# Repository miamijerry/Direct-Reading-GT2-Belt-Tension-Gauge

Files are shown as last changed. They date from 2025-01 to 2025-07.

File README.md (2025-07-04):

# 7/4/2025 Added 
# Relative Magnet Force Comparator



# and
# Super Simply Magnet Force Measurement Tool



# _________________________________________________________________________

# _________________________________________________________________________

# 7/1/2025 Added files to convert this GT2 belt tension gauge to a Magnet Force Measurement Tool

10x5mm N52 magnet from JC Magnetics

# 10x5mm N52 magnet from JC Magnetics being measure for actual repelling force in lbs.



# _________________________________________________________________________

# _________________________________________________________________________

# V2 of Direct Reading GT2 Belt Tension Gauge







# Direct-Reading-GT2-Belt-Tension-Gauge
A method to accurately determine GT2 belt tension

Math Formula

Per the 1/64 deflection per inch of belt method

I created three STL's for V2; Front Pins, Sled, and Deflection Knob. These mount a Force Gauge

To set the amount of belt deflection, I am using a #10-32 threaded rod attached to the Deflection Knob

Each 1/2 turn of a #10-32 screw equals 1/64 of an inch.

The first beta version was not accurate, and it was determined that the friction of the belt against the pins was creating incorrect reading.

The first working version (V1) assembly used GT2 idler pulleys for the pins. The results have been within 0.2 pounds.

I am not releasing V1, because V2 was much better.

Thanks to DIYshift, who's tension gauge was used to model the Front stl.

https://github.com/Diyshift/3D-Printer/tree/main/GT2%20Belt%20Tension%20Meter

# Recommended GT2 Belt Tension

Hard to find this information, 

From https://www.sdp-si.com/D265/PDF/D265T050.pdf

Recommended Tension

and

From https://github.com/Diyshift/3D-Printer/blob/main/GT2%20Belt%20Tension%20Meter/Manual/GT2_Tensiometer_Manual.pdf

DIYshift tension guideline; 
# Voron - A/B 6mm Belts Min 2.0 lbs Max 3.5 lbs, Voron belted Z 9mm belt min 4.5 lbs Max 6.0 lbs

# Verifying that this gauge is reading correctly

Hang a known weight from a section of GT2 belt

Following operating procedure

Verify that the gauge reports the same value as the known weight

# License
Shield: [][cc-by-nc-sa]![Recommended Tension]

This work is licensed under a
[Creative Commons Attribution-NonCommercial-ShareAlike 4.0 International License][cc-by-nc-sa].

[][cc-by-nc-sa]

[cc-by-nc-sa]: http://creativecommons.org/licenses/by-nc-sa/4.0/
[cc-by-nc-sa-image]: https://licensebuttons.net/l/by-nc-sa/4.0/88x31.png
[cc-by-nc-sa-shield]: https://img.shields.io/badge/License-CC%20BY--NC--SA%204.0-lightgrey.svg

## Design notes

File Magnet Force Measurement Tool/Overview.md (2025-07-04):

Convert the GT2 Belt Tension Gauge to a precise Magnet Force Measurement Tool

10x5mm N52 magnet from JC Magnetics

There are two types of inner magnet carriers, one internally threaded and one slip on.

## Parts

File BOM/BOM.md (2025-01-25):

Direct Reading 2GT Belt Tension Meter V2

Bill of Material

1ea 10-32 heat insert 10-32 x 3/8 tall x 7.1mm diameter (Set in the Sled)
1ea 10-32 x 6" Threaded Rod, will cut shorter
2ea M4 x 6mm flat head countersunk screw (Attaches Force Gauge)
2ea M4 x 6mm Socket Head Screw screw (Attaches Force Gauge and acts as a stop)
1ea 50N Digital Force Gauge Push Pull Gauge Portable Force Meter with Units N/LB/Kg/Oz, 
Auto Backlit LCD, for Lab Tension and Compression Load Plug Force Destructive Tests.
https://www.amazon.com/dp/B09V11R7Y2?ref=ppx_yo2ov_dt_b_fed_asin_title&th=1
3ea 10-32 fiber locknuts
2ea M5 washers aprox 14mm OD (To create a thrust surface on the Sled stl) 

Front Heat Insert
2ea M3 x 8mm tall x 4.7 diameter heat insert
2ea 3.1mm ID x 5mm OD x 10mm tall M3 spacer
https://www.amazon.com/dp/B0CQDWT42S?ref=ppx_yo2ov_dt_b_fed_asin_title&th=1
2ea M3 washers 9mm OD
2ea M3 x 18mm socket head cap screw
2sets GT2 Idler Pulleys, 2ea smooth and 2ea with teeth
https://www.amazon.com/gp/product/B0B1ZH9WC5/ref=ppx_yo_dt_b_asin_title_o04_s00?ie=UTF8&th=1

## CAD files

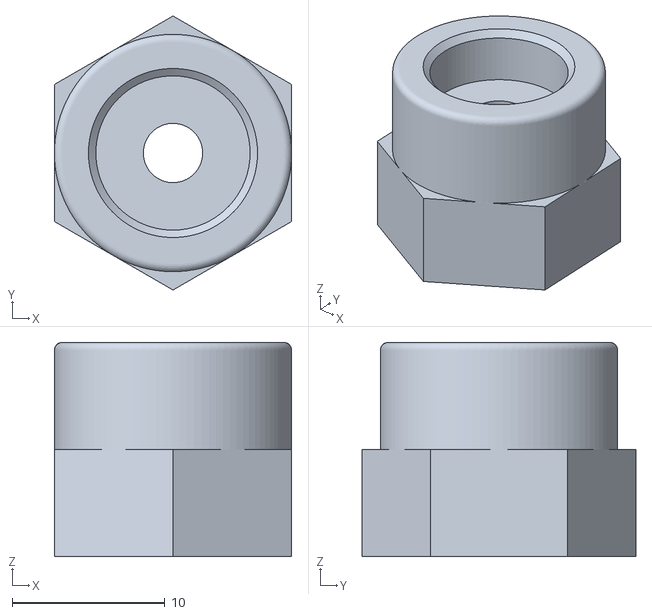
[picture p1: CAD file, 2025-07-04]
Magnet Force Measurement Tool/97_Percent_Scaled_R2_10x5mm internally threaded magnet carrier.stl
15.5 x 17.9 x 14.0

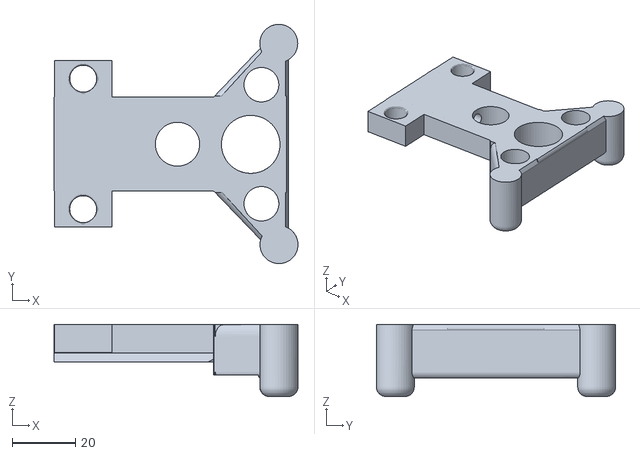
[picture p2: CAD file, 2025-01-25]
R4_Front_Heat_Insert_V2.stl
77.0 x 75.5 x 22.7

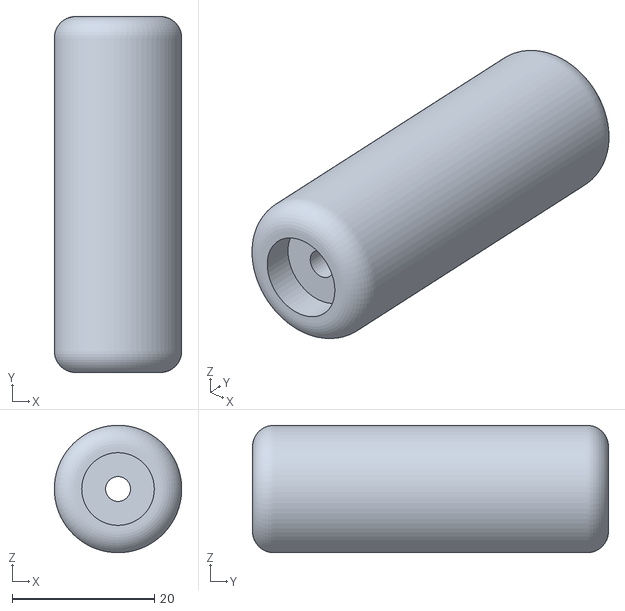
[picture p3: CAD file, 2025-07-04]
Super Simple Magnet Force Tester/R2_10x5mm magnet PCV pipe carrier sized for one half inch schedule 20 PVC pipe.stl
17.9 x 50.0 x 17.9

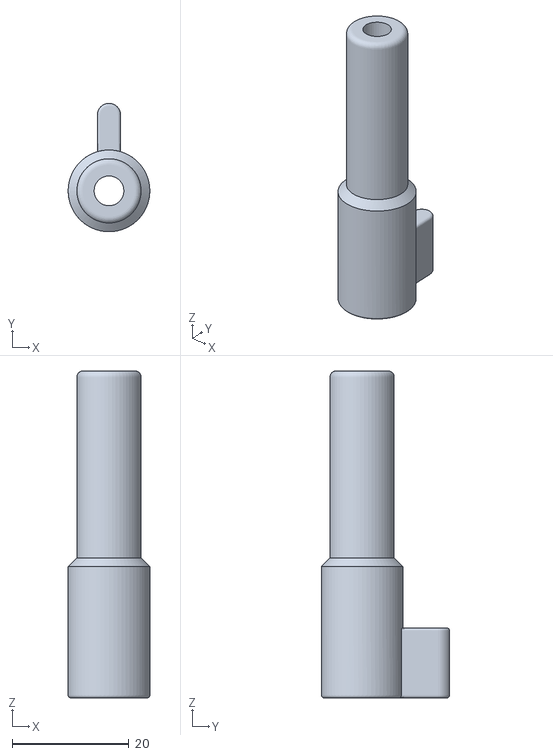
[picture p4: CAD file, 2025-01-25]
Deflection_Knob.stl
14.0 x 22.0 x 56.0

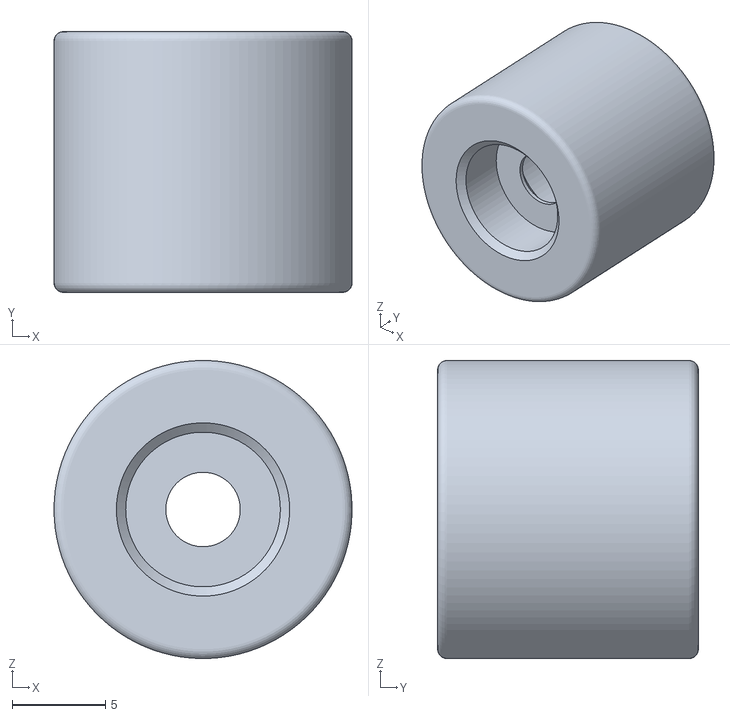
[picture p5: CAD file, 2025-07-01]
Magnet Force Measurement Tool/8x5mm magnet carrier.stl
16.0 x 14.0 x 16.0

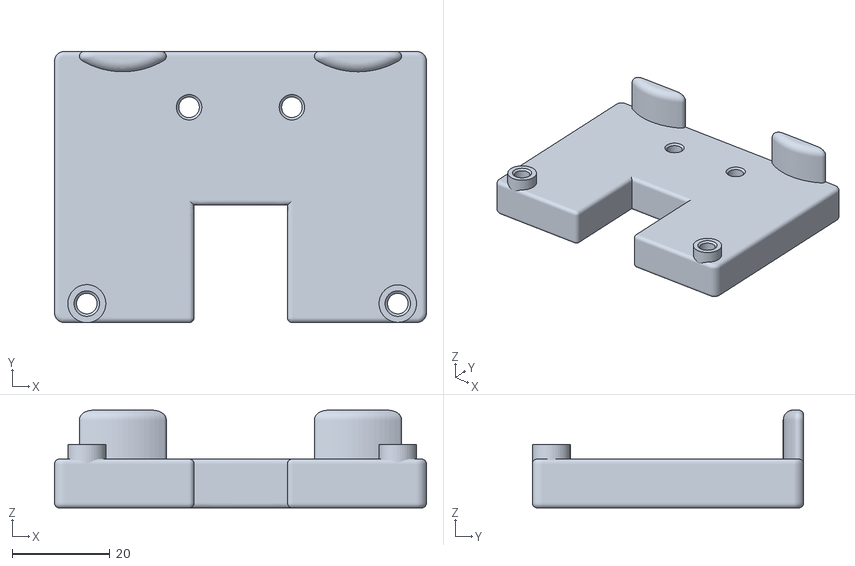
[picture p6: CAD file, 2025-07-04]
Relative Magnet Force Comparator/Baseplate.stl
76.0 x 55.4 x 20.0

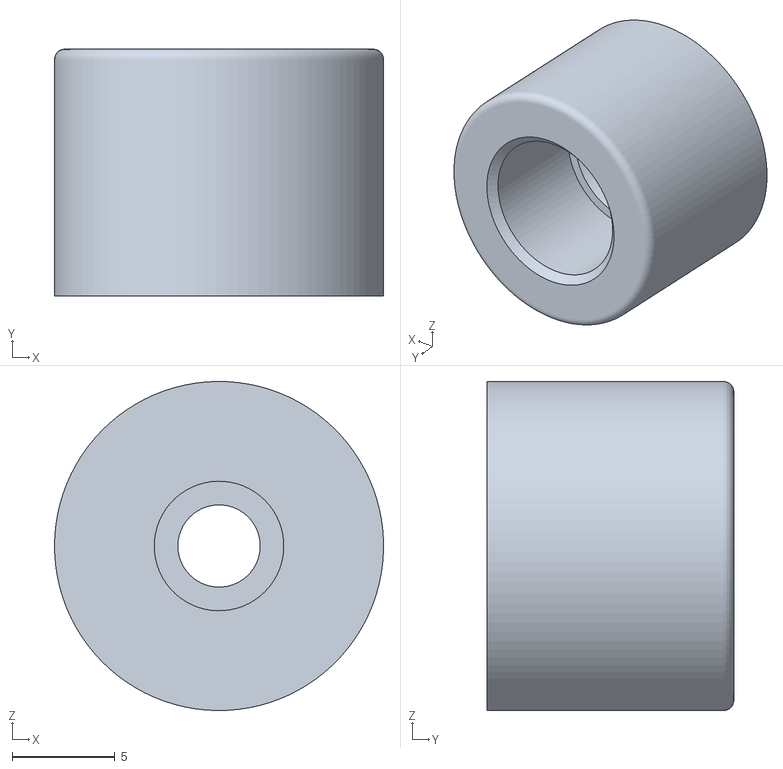
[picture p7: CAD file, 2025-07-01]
Magnet Force Measurement Tool/6x3mm magnet carrier.stl
16.0 x 12.0 x 16.0

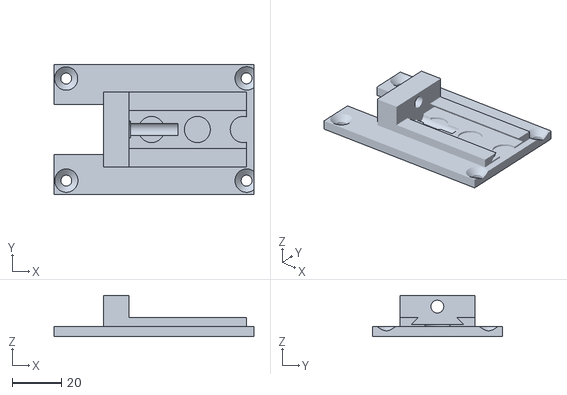
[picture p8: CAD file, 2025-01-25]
R4_Sled_V2.stl
81.0 x 52.5 x 16.6

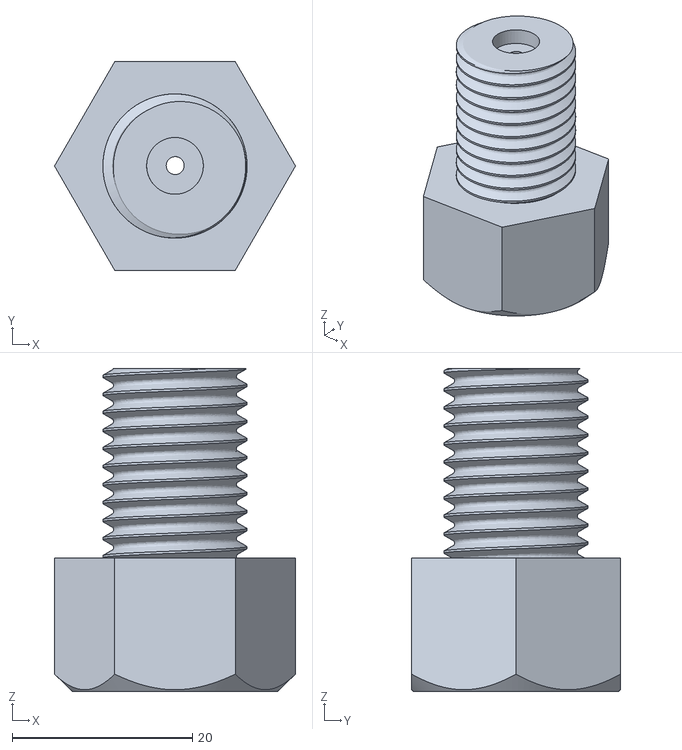
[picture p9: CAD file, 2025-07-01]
Relative Magnet Force Comparator/R6_6x3mm magnet threaded carrier.stl
26.7 x 23.2 x 35.8

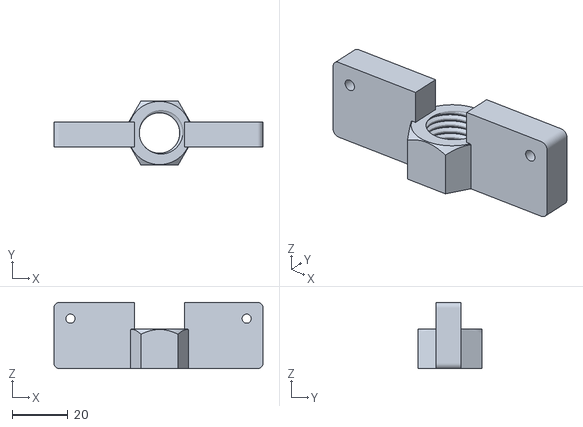
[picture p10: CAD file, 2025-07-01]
Relative Magnet Force Comparator/R4_Threaded_Bridge.stl
75.3 x 23.2 x 23.9

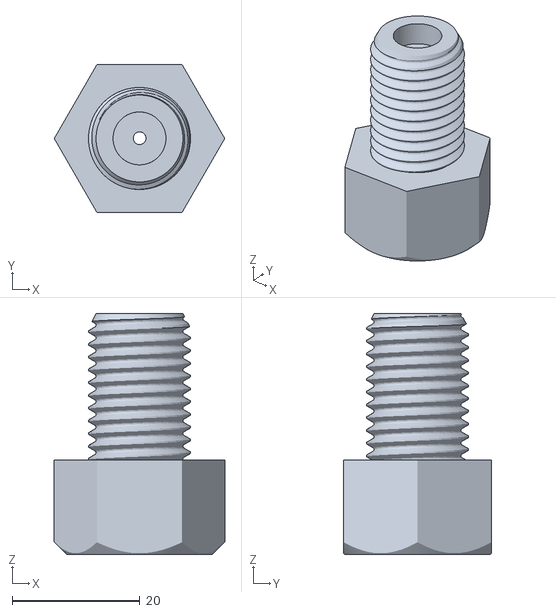
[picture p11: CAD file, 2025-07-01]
Relative Magnet Force Comparator/R5_8x5mm magnet threaded carrier.stl
26.7 x 23.2 x 37.8

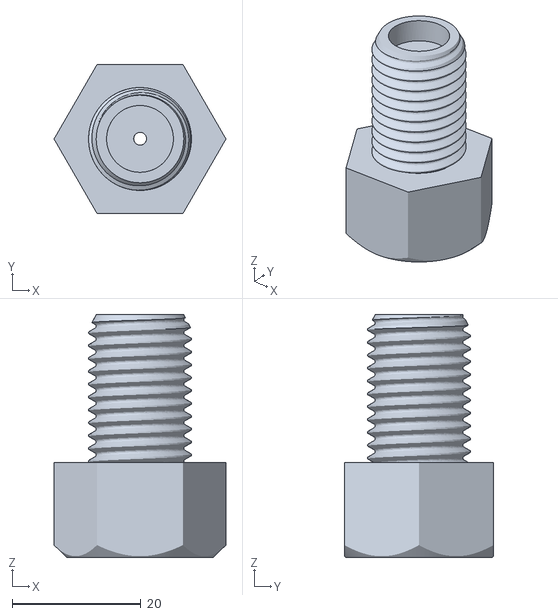
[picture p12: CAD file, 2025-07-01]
Relative Magnet Force Comparator/R5_10x5mm magnet threaded carrier.stl
26.7 x 23.2 x 37.8

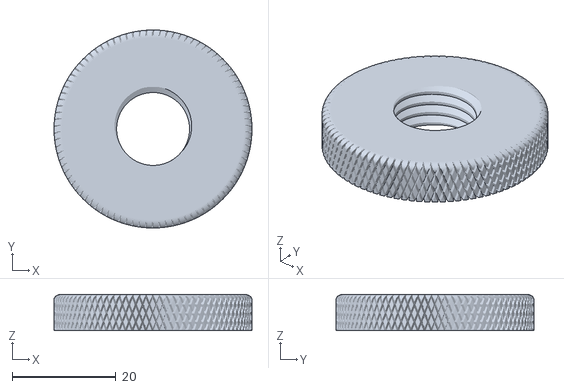
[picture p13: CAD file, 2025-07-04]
Relative Magnet Force Comparator/M16 Knurled Jam Nut.stl
38.1 x 38.1 x 7.00

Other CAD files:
Magnet Force Measurement Tool/R2_10x5mm magnet carrier.stl

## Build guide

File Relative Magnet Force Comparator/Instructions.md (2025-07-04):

Create a "Relative Magnet Force Comparator" from YesterdaysCoffee Belt Tension Meter;
https://www.printables.com/model/634190-gt2-belt-tension-meter-wbearings

# Tool is only for comparing magnets, will show relative weaker or stronger magnets then the magnet used to set the pointer.



Parts needed to assemble this tool.



Mount the Belt Tension Meter to the printed Backplate with longer screws M3x18mm work fine. (Note the M6x10 stainless grub screw threaded into the YeasterdaysCoffer meter, this grub screw should be nylon and more like M6x14mm long)



Advance the thread magnet carrier until the pointer reads 3.0 (This is relative, only good for comparating) 

M16 Knurled Jam Nut

At this point the threaded carrier needs to be set to this depth with a jam nut.

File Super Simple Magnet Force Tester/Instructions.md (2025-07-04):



1) Start with a tube, a plunger, two magnet carriers and any digital scale. (In this picture I am using 390mm long 1/2" schedule 20 PVC water pipe for the tube)

  

2) I glued the two magnets in the carriers with RTV adhesive with magnets repelling, place first carrier in tube.



3)  Place the second carrier in the tube with magnets repelling.



4) Place plunger in the tube and depress everything solid against an object and mark the plunger height.



5) A carrier should now extend from the tube like a spring.



6) Press the tool against a scale and depress the carrier into the tube til the tube is ABOUT to touches the scale, note the repelling force of the magnet

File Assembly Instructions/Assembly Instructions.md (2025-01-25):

Verify that the front and sled dovetails slide together with low force

1) The Front stl needs 2ea M3 X 8mm Tall heat inserts install where the pins (Idler Pulleys) mount.
2) Install 10-32 x 3/8 heat insert into the Front stl hole that runs thru the center of dovetail.
3) Install the two Idler pulley to the Front by ; 2ea 3.1 x 5 x 10mm spacers, 2ea M3 x 16mm screws, 2ea M3 x 9mm OD washers
4) Super glue 2ea M5 washer Aprox 14mm OD to the Sled stl where the 10-32 threaded rod passes thru. (See picture)
5) Deflection Knob stl assembly; 
a) Hold the threaded rod with vise grips about 15mm from one end
b) Run one 10-32 fiber locknut on the threaded rod, flush with one end
c) Install the thread rod so that the one installed nut can move into the hex cutout in the knob
d) Pull the rod out enough to hold again with the vise grip.
e) install another fiber locknut on the opposite end of the threaded rod.
f) Run the second locknut to about 10mm shy of clamping the Deflection Knob
g) Slide the thread rod, so that the first nut comes out of the hex cutout
h) Apply Super Glue to the first locknut and the threads near the locknut
i) Run the second locknut down, clamping the Deflection Knob
j) Now we have a Deflection Knob Threaded Screw, cut this to a exposed thread length of ???
6) Install the Deflection Knob Threaded Screw into the hole in the Sled, secure with a third locknut. tighten so the knob can still turn
7) Mount the Sled stl to the Force Gauge with 2ea M4 x 6mm flat head countersunk screws at the knob end.
8) Slide the Front stl onto the dovetail of the Sled, while rotating the Delection Knob. run the knob down drawing the Front back
9) Install 2ea M4 x 6mm socket head screws in the remaining two holes attaching the Sled to the Force Gauge (these are intended to act as stops)
10) Install the chisel tip on the Force Gauge with a dab of locktite. (See pictures when posted)

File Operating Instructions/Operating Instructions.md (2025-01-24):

1) Turn the deflection knob counter clockwise until it hits the stops.

2) Assemble the "Direct Reading GT2 Belt Tension Gauge on the center of the belt span

3) Set the Force Gauge to read pounds, slowly turn the Deflection Knob clockwise until the Force Gauge reads appoximately 0.10 pounds

4) Determine the length of the belt span in inches, divide these inches by 2 to get the number of turns of the Deflection Knob 
to get the 1/64 inch of belt deflection per inch that is required (IE 17 inch span would equal 8.5 turns) 

5) Rotate the Deflection Knob clockwise the number of turns determined in step 4

Read your belt tension on the Force Gauge in whatever unit you want. (IE pounds, Newtons, etc)

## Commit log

2025-01-24 Create BOM
2025-01-24 Update BOM
2025-01-24 Create Assembly Instructions
2025-01-24 Update Assembly Instructions
2025-01-25 Rename Assembly Instructions to Assembly Instructions.md
2025-01-25 Update and rename Assembly Instructions.md to Assembly Instructions
2025-01-25 Update and rename BOM.md to BOM
2025-07-01 Create Magnet Comparator Adapter
    For using the GT2 belt gauge as a magnet comparator
2025-07-01 Add files via upload
    Files for Magnet Comparator
    [6x3mm magnet carrier.stl, 8x5mm magnet carrier.stl, R2_10x5mm magnet carrier.stl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]
2025-07-01 Rename 6x3mm magnet carrier.stl to Magnet Comparator/6x3mm magnet carrier(1).stl
    [6x3mm magnet carrier(1).stl]
2025-07-01 Rename 8x5mm magnet carrier.stl to Magnet Comparator/8x5mm magnet carrier(1).stl
    [8x5mm magnet carrier(1).stl]
2025-07-01 Rename Magnet Comparator Adapter to Magnet Comparator/Magnet Comparator Adapter(1)
2025-07-01 Rename R2_10x5mm magnet carrier.stl to Magnet Comparator/R2_10x5mm magnet carrier(1).stl
    [R2_10x5mm magnet carrier(1).stl]
2025-07-01 Rename R4_Threaded_Bridge.stl to Magnet Comparator/R4_Threaded_Bridge(1).stl
    [R4_Threaded_Bridge(1).stl]
2025-07-01 Rename R5_10x5mm magnet threaded carrier.stl to Magnet Comparator/R5_10x5mm magnet threaded carrier(1).stl
    [R5_10x5mm magnet threaded carrier(1).stl]
2025-07-01 Rename R5_8x5mm magnet threaded carrier.stl to Magnet Comparator/R5_8x5mm magnet threaded carrier(1).stl
    [R5_8x5mm magnet threaded carrier(1).stl]
2025-07-01 Rename R6_6x3mm magnet threaded carrier.stl to Magnet Comparator/R6_6x3mm magnet threaded carrier(1).stl
    [R6_6x3mm magnet threaded carrier(1).stl]
2025-07-04 Update and rename Information to Magnet Force Measurement Tool
2025-07-04 Rename Magnet Comparator/6x3mm magnet carrier(1).stl to Magnet Force Measurement Tool
2025-07-04 Rename Magnet Force Measurement Tool to Magnet Force Measurement Tool /Readme
2025-07-04 Rename R2_10x5mm magnet PCV pipe carrier.stl to R2_10x5mm magnet PCV pipe carrier sized for one half inch scedule 20 PVC pipe.stl
    [R2_10x5mm magnet PCV pipe carrier sized for one half inch scedule 20 PVC pipe.stl]
2025-07-04 Rename R2_10x5mm magnet PCV pipe carrier sized for one half inch scedule 20 PVC pipe.stl to R2_10x5mm magnet PCV pipe carrier sized for one half inch schedule 20 PVC pipe.stl
    [R2_10x5mm magnet PCV pipe carrier sized for one half inch schedule 20 PVC pipe.stl]
